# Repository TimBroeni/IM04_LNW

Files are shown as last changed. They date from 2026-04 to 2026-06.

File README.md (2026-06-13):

# Sortino

## Inhaltsverzeichnis

- [Kurzbeschreibung des Projekts](#kurzbeschreibung-des-projekts)
- [UX & Konzeption](#ux--konzeption)
- [Setup](#setup)
- [Technische Details](#technische-details)
- [Known bugs](#known-bugs)
- [Umsetzungsprozess](#umsetzungsprozess)

## Kurzbeschreibung des Projekts

* **Modul:** Interaktive Medien 4 an der Fachhochschule Graubünden (FS26)  
* **Themenfeld:** IoT-Applikation zum Thema Eltern mit kleinen Kindern  
* **Name des Projekts:** Sortino   
* **Team Physical Computing:** Carlo Pierotto & Luc Guerraz
* **Team WebApp:** Tim Brönimann, Tim Eberbard

Kinder räumen ungerne ihr Zimmer auf und Eltern haben es gern wenn es am Abend aufgeräumt ist. 
Unsere Kiste motiviert Kinder zum aufräumen, sie erlässt jeden Abend um 18:30 einen Reminder zum aufräumen und um 19:00 einen Lob oder eine Ermahnung ja nach dem ob aufgeräumt worden ist oder nicht.
Die Kiste erkennt Spielzeuge anhand des Gewichts. 
Über die Web-App können die Eltern einsehen, welche Spielzeuge gerade ausserhalb der Kiste sind, und welches die beliebtesten Spielzeuge sind.

* **WebApp:** [https://im04.tim-broenimann.ch](https://im04.tim-broenimann.ch)  
* **Video-Dokumentation:** [Link zum Video auf Youtube](https://www.youtube.com/watch?v=574Dd3WErXQ) 

## UX & Konzeption

*In diesem Teil werden die gemeinsamen Schritte aus der UX-Abgabe dokumentiert, damit sich hier alles vollständig an einem Ort befindet (betrifft WebApp und Physical Computing)*

### Figma:
[Link zum Figma](https://www.figma.com/design/I6OaVpQoHoBlVxiTwrd5Yo/App-Konzeption?node-id=0-1&t=EXwHhpwK3AQBsHQe-1)
### User Flow \+ Screen Flow (Screenshot aus Figma)
User Flow + Screen Flow
### Weitere Ergänzungen

#### Welche Features waren angedacht? 

##### Folgene Features wurden umgesetzt:

Die Aktuelle Webapp, so wie sie jetzt steht, enthält die Basis unserer geplanten Features. Die Webapp erlaubt es eine Spielzeugkiste zu haben, die jederzeit weiss, welche Spielzeuge akteull in der Spielzeugkiste sind und welche nicht. Anhand des Gewichts des Spielzeuges erkennt die Kiste, ob ein Speilzeug gerade in der Kiste ist oder nicht. Über die Spielzeug-Seite können die Spielzeuge verwaltet werden. Man kann neue Spielzeuge hinzufügen, ihnen neue Namen geben oder Spielzeuge wieder löschen (wenn man sie z.B. verkauft hat). Dort sieht man ebenfalls einen Überblick über die Nutzungshäufigkeit der Spielzeuge. In den Einstellungen kann ich mein Profil bearbeiten und meinen Haushalt verwalten. Das heisst, ich kann meinem Haushalt Kisten hinzufügen. Auf der Seite sehe ich meinen Haushaltscode mit welchem andere Erziehungsberechtigte meinem Haushalt beitreten können. Diese kann ich in den Einstellungen auch wieder entfernen (z.B. wenn sich die Eltern getrennt haben😢). Die Webapp wie sie jetzt entwickelt ist, ist für die Erziehungsberechtigten entwickelt. Somit kann die Bildschirmzeit der Kinder reduziert werden.

##### Und, folgende Features wurden nicht umgesetzt:

|Feature|Teil|Erklärung|
|-|-|-|
|Erkennung über RFID|MC|In der ersten Konzeptionsphase war die Idee, die spielzeuge anhand eines RFID-Chips zu erkennen. Über mehrere Antennen hätte die Box das Spielzeug automatisch erkennen sollen, wenn das Spielzeug mit dem Chip in die Box gesetzt wird.|
|Rollen für User|WebApp|Im Ursprünglichen System. Eltern erhalten Admin-Rechte für die Web-App. Kinder benötigen nicht zwingend Zugriff auf die Webapp, jedoch ist in der Webapp ersichtlich, welches Kind wie viele Punkte hat (also wie gut es aufträumt). Damit das System funktioniert, hätte die Box nicht einem Haushalt sondern einem User zugewiesen werden müssen. Die Punkte kann das Kind sammeln und gegen Belohnungen einlösen. Weil das Punktesystem wegfiel und Kisten direkt dem Haushalt hinzugefügt wurden, fiel das Rollensystem weg. Kinder können ohne Umstände die Box benutzen während die Eltern Kontrolle über die Box haben.|
|Gamification|WebApp|Punkte sammeln:<br>Jeden Abend um eine vordefinierte Uhrzeit gibt die Box ein Signal, dass es bald Zeit ist, aufzuräumen. Nach ca. 30 Minuten kontrolliert die Webapp automatisch, ob heute Spielzeuge genutzt wurden und ob alle Spielzeuge in der Kiste sind. Wenn zu diesem Zeitpunkt alles aufgeräumt ist, erhält das Kind einen Punkt. Über die Webapp können die Eltern mit ihren Adminrechten im Punkteverlauf ebenfalls Punkte hinzufügen, wenn das Kind z.B. im Haushalt mal ausserordentlich mitgeholfen hat. Die Eltern können dort ebenfalls erhaltene Punkte wieder löschen. Sowohl auf der Webapp wie auch auf dem physischen Display an der Box ist ersichtlich, wie viele Punkte gesammelt wurden und wie nah man an den Belohnungen ist. Dieses Feature wurde gestrichen um den Rahmen des Projektes nicht zu sprengen, weil die Webapp schon genug Features hatte und der Aufwand zu gross geworden wäre.<br><br>Punkte einlösen:<br>Über die Belohnungsseite können die Eltern für einen Haushalt Belohnungen definieren und die Belohnung den Kindern zuweisen. Die Eltern können festlegen, wie viele Punkte eine Belohnung kosten soll. Hat das Kind eine Belohnung eingelöst, müssen es die Eltern über die Webapp einlösen. Die Punkte werden vom aktuellen Punktestand abgezogen. Weil die Gamification weg fiel wurde das Belohnungssystem ebenfalls gestrichen.|
|Gamification|MC|Lange war geplant, der Box ein Aufräum-Feature zu verpassen. Dabei schlägt die Box vor, welches Spielzueg als nächstes eingeräumt werden sollte. Schafft man es innerhalb einer gweissen Ziet, erhält das Kind zusätzliche Punkte. Z.B. steht "Bring mir als nächstes das Piratenschiff" und ein Countdown. Dabei priorisiert die Box schwere Spielzeuge zuerst (siehe nächstes Feature). Dieses Feature wurde gestrichen um den Rahmen des Projektes nicht zu sprengen, weil die Webapp und MC schon genug Features hatte und der Aufwand zu gross geworden wäre.|
|Kategorien für Spielzeuge|WebApp|Ursprünglich war gedacht, dass man beim hinzufügen eines Spielzeuges klassifizierungen geben kann, z.B. ob ein Spielzeug schwer oder fragile ist. In der Aufräum-Gamification hätte die Box priorisieren sollen, zuerst schwere Spielzeuge einzuräumen und erst dann die leichten, welche schnell kaputt gehen können. Weil die Box-Gamification weg fiel, wurde diese Angabe bei den Speilzeugen entfernt. Das gewicht wird lediglich genutzt, weil anhand des Gewichts das jeweilige Spielzeug erkannt wird. Dieses Feature wurde nicht eingebaut, weil die Gamification weg fiel. Die Box musste nicht mehr zwingend wissen, welche Spielzeuge zuerst eingeräumt werden müssen. Deswegen wurde dieses Feature überflüssig.|
|Kontrolle über Gamification|WebApp|In der Webapp sollte es in einem Haushalt mehrere Rollen geben. Eltern hätten Admin-Rechte und könnten Einstellungen an der Gamification vornehmen z.B. wie viel Punkte das Kind fürs Aufräumen bekommt, wie viele Punkte eine Belohnung kostet, wann der Stichzeitpunkt wo die Kiste kontrolliert, ob alles versorgt ist und man hätte einstellen können, wie hoch die Toleranz ist, wie viele Spielzeuge über nach draussen bleiben dürfen. Das Kind hätte dann trotzdem einen Punkt erhalten, auch wenn z.B. zwei Spielzeuge nicht eingeräumt sind. Die Gamification hätte man auch vollkommen deaktivieren können. Dann würde das Punktesystem für den Entsprechenden Haushalt deaktiviert sein. Weil die Gamification weg fiel müssen die Game-Settings nicht mehr eingestellt werden.|

## Setup

### Installationsanleitung WebApp

#### Infrastruktur + Installation
Für die Webapp wird ein Hosting mit einer Domain benötigt. Als Beispiel eignen sich Anbieter wie Infomaniak oder Hostpoint. Dort laufen sowohl die Webseite als auch die Datenbank. Die Webapp selbst besteht aus PHP, JavaScript sowie HTML/CSS.
Zusätzlich wird eine MySQL-Datenbank benötigt, welche über das Hosting erstellt werden kann. Der Zugriff auf die Datenbank erfolgt über phpMyAdmin. Damit sich die Webseite mit der Datenbank verbinden kann, müssen die Zugangsdaten in der Datei config.php eingetragen werden. Dazu gehören der Host, der Datenbankname, der Benutzername sowie das Passwort.
Wichtig ist, dass die config.php Datei nicht öffentlich auf GitHub hochgeladen wird, da sie sensible Zugangsdaten enthält. Deshalb sollte sie über die .gitignore Datei ausgeschlossen werden.
Für die Zusammenarbeit im Team wurde GitHub verwendet. Alternativ könnte auch eine andere Plattform zur Versionsverwaltung genutzt werden. Der Code kann anschliessend über eine SFTP-Verbindung direkt auf den Webserver hochgeladen und synchronisiert werden.
Die physische Sortino-Box benötigt ausserdem eine Stromversorgung sowie eine WLAN-Verbindung aus dem Haushalt, damit sie mit der Datenbank kommunizieren kann.

#### Datenbank importieren und verbinden
Die Datenbank kann direkt über das Hosting erstellt werden. Danach werden die benötigten Tabellen in die Datenbank importiert. In unserem Fall enthält die Datenbank unter anderem Tabellen für Haushalte, Benutzer:innen, Kisten sowie Spielzeuge und das Heraus-/Zurücklegen der Spielzeuge.
Im Projekt befindet sich zusätzlich eine db.sql Datei. Diese enthält die Struktur der gesamten Datenbank und kann über phpMyAdmin importiert werden. Dadurch werden alle benötigten Tabellen automatisch erstellt.
Damit die Webapp auf diese Daten zugreifen kann, muss die Verbindung in der config.php Datei eingerichtet werden. Dort werden die Zugangsdaten der Datenbank eingetragen. Dazu gehören der Host, der Datenbankname, der Benutzername und das Passwort.
Nach der erfolgreichen Verbindung kann die Webapp Daten lesen und neue Informationen abspeichern. Dazu gehören beispielsweise neue Haushalte, registrierte Kisten oder die gespeicherten Gewichte der Spielzeuge.
Die Kommunikation zwischen der Sortino-Box und der Webapp läuft über die Datenbank. Die Box speichert neue Informationen direkt dort ab. Die Webapp liest diese Daten anschliessend aus und stellt sie für die Eltern übersichtlich dar.
Dadurch kann später angezeigt werden:
•	welche Spielzeuge momentan fehlen
•	wann ein Spielzeug zuletzt verwendet wurde
•	wie oft ein Spielzeug aus der Kiste genommen wurde
•	welche Kisten zu einem Haushalt gehören
Ein Haushalt kann mehrere Kisten besitzen. Die Daten (Spielzeuge) aller Kisten werden anschliessend gemeinsam in der Webapp dargestellt.

#### Erststart der Webapp und Einrichtung
Nach dem Kauf der Sortino-Box besucht der User zuerst die Sortino-Webseite. Die Startseite der Webapp ist gleichzeitig die Login- und Registrierungsseite.
Zuerst wird ein Benutzerkonto mit Name, E-Mail-Adresse und Passwort erstellt. Nach dem ersten Login erkennt die Webapp, dass der Account noch keinem Haushalt zugeordnet ist.
Anschliessend kann entweder einem bestehenden Haushalt über einen Code beigetreten oder ein neuer Haushalt erstellt werden. Beim Erstellen eines neuen Haushalts wird dessen Name in der Datenbank gespeichert und mit einer eigenen household_id versehen.
Danach kann die gekaufte Sortino-Box hinzugefügt werden. Dazu wird die Seriennummer verwendet, welche auf der Unterseite der Box eingraviert ist. Diese Seriennummer ist bereits in der Datenbank vorhanden, jedoch noch keinem Haushalt zugewiesen.
Sobald die Kiste erfolgreich verbunden wurde, kann ihr ein eigener Name gegeben werden. Dies ist beispielsweise sinnvoll, wenn mehrere Kinder oder mehrere Kisten in einem Haushalt vorhanden sind.
Im letzten Schritt können Spielzeuge hinzugefügt werden. Dafür wird einem Spielzeug zuerst in der Webapp ein Name gegeben. Anschliessend wird das Spielzeug in die Kiste gelegt. Die Box erkennt die Gewichtsveränderung und speichert diese zusammen mit der passenden household_id in der Datenbank ab.
Dadurch kann später erkannt werden, wann ein Spielzeug aus der Kiste genommen oder wieder zurückgelegt wurde.

### Bauanleitung Physical Computing

Um das physische Artefakt nachbauen zu können muss mann die Komponenten nach Komponentenliste & Steckplan zusammen bauen. Danach müssen die WLAN Credentials in der `sortino_OS.ino`-Datei hinterlegt werden, sie muss anschliessend kompiliert werden und auf das Microcontroller hochladen werden.

#### Komponenten
- ESP32C6
- OLED Display
- MP3 Player mit Lautsprecher
- LED Ring (12 LEDs)
- Gewichtssensor

Der ESP32C6 ist das Kernstück, woran alle Physischen Komponenten verbunden werden.
Im Steckplan sieht man, an welche Pins, welche Komponenten angeschlossen werden.

#### Steckplan
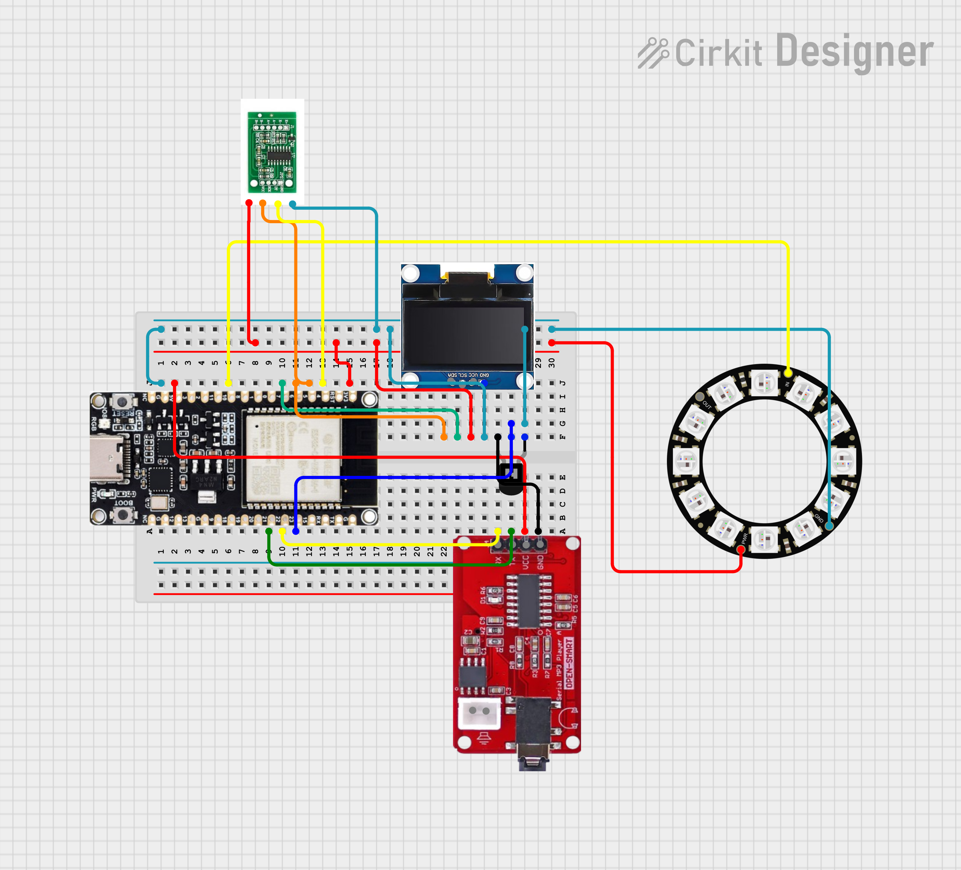
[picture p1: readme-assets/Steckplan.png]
Steckplan


#### Programme

|Datei|Rolle|
|--|--|
|`sortino_OS.ino`|Das Hauptprogramm, welches Setup und Loop festlegt. Im Setup wird die WLAN-Verbindung erstellt und sowohl der Gewichtssensor als auch der Audioplayer initialisiert. In der Loop wird die Uhrzeit überprüft, um den Aufräum-Reminder auszulösen. Es wird nach Gewichtsänderungen überprüft, um das Reinlegen oder Herausnehmen von Spielzeugen zu erfassen. Ebenso wird nach dem `add_mode` überprüft, um neue Spielzeuge zu erfassen.|
|`cJSON/cJSON.c`|Arduino JSON Library|
|`cJSON/cJSON.h`|Arduino JSON Library|
|`Adafruit_BusIO_Register.cpp`|Arduino Adafruit GFX dependency. Arduino Adafruit Bus IO Library|
|`Adafruit_BusIO_Register.h`|Arduino Adafruit GFX dependency. Arduino Adafruit Bus IO Library|
|`Adafruit_GenericDevice.cpp`|Arduino Adafruit GFX dependency. Arduino Adafruit Bus IO Library|
|`Adafruit_GenericDevice.h`|Arduino Adafruit GFX dependency. Arduino Adafruit Bus IO Library|
|`Adafruit_GFX.cpp`|OLED Display funktionalität. Arduino Adafruit GFX Library|
|`Adafruit_GFX.h`|OLED Display funktionalität. Arduino Adafruit GFX Library|
|`Adafruit_I2CDevice.cpp`|Arduino Adafruit GFX dependency. Arduino Adafruit Bus IO Library|
|`Adafruit_I2CDevice.h`|Arduino Adafruit GFX dependency. Arduino Adafruit Bus IO Library|
|`Adafruit_I2CRegister.h`|Arduino Adafruit GFX dependency. Arduino Adafruit Bus IO Library|
|`Adafruit_NeoPixel.cpp`|LED Ring funktionalität. Arduino Adafruit NeoPixel Library|
|`Adafruit_NeoPixel.h`|LED Ring funktionalität. Arduino Adafruit NeoPixel Library|
|`Adafruit_SPIDevice.cpp`|Arduino Adafruit GFX dependency. Arduino Adafruit Bus IO Library|
|`Adafruit_SPIDevice.h`|Arduino Adafruit GFX dependency. Arduino Adafruit Bus IO Library|
|`Adafruit_SSD1306.cpp`|OLED Display funktionalität. Arduino Adafruit SSD1306 Library|
|`Adafruit_SSD1306.h`|OLED Display funktionalität. Arduino Adafruit SSD1306 Library|
|`Arduino_JSON.h`|Arduino JSON Library|
|`audioplayer.h`|Audio player funktionalität. Diese Datei wird in mc.ino eingebunden.|
|`esp.c`|LED Ring funktionalität. Arduino Adafruit NeoPixel Library|
|`gfxfont.h`|OLED Display funktionalität. Arduino Adafruit GFX Library|
|`glcdfont.c`|OLED Display funktionalität. Arduino Adafruit GFX Library|
|`HX711.cpp`|Gewichsensor funktionalität. Arduino HX711 Library|
|`HX711.h`|Gewichsensor funktionalität. Arduino HX711 Library|
|`JSON.cpp`|Arduino JSON Library|
|`JSON.h`|Arduino JSON Library|
|`JSONVar.cpp`|Arduino JSON Library|
|`JSONVar.h`|Arduino JSON Library|
|`splash.h`|OLED Display funktionalität. Arduino Adafruit SSD1306 Library|

#### Kommunikationswege / API Schnittstellen

##### Kisten status abfragen (`api/physical/lib/get/add.php`)
Wird alle 3 Sekunden abgefragt, um zu wissen ob die Kiste neue Spielzeuge jetzt messen muss
```bash
curl -X GET 'https://im04.tim-broenimann.ch/api/physical/[seriennumer]/add'
```
```json
{
  "status": "success",
  "data": {
    "add_mode": false
  }
}
```

##### Spielzeug hinzufügen, gewicht erfassen (`api/physical/lib/post/add.php`)
Wird abgefragt, um das Gewicht eines neues Spielzeug zu erfassen
```bash
curl -X POST 'https://im04.tim-broenimann.ch/api/physical/[seriennumer]/add' \
  --header 'Content-Type: application/json' \
  --data '{"weight": 140}'
```
```json
{
  "status": "success",
  "data": {
    "name": "Neues Spielzeug Name"
  }
}
```

##### Spielzeug wird in kiste gelegt/herausgenommen (`api/physical/lib/post/event.php`)
Wird abgefragt, um eine Gewichtänderung in der Kiste zu erfassen.
```bash
curl -X POST 'https://im04.tim-broenimann.ch/api/physical/[seriennumer]/event' \
  --header 'Content-Type: application/json' \
  --data '{"weight": 87.0}'
```
```json
{
  "status": "success",
  "data": {
    "name": "Spielzeug Name",
    "movement": 1
  }
}
```

##### Sind alle Spielzeuge in der Kiste (`api/physical/lib/get/status.php`)
Wird abgefragt, um zu wissen ob alle Spielzeuge in der Kiste sind und zu wissen wieviele fehlen/da sind
```bash
curl -X GET 'https://im04.tim-broenimann.ch/api/physical/[seriennumer]/status'
```
```json
{
  "status": "success",
  "data": {
    "all_in_box": true,
    "in_box": 14,
    "out_box": 0
  }
}
```

## Technische Details

### Komponentenplan

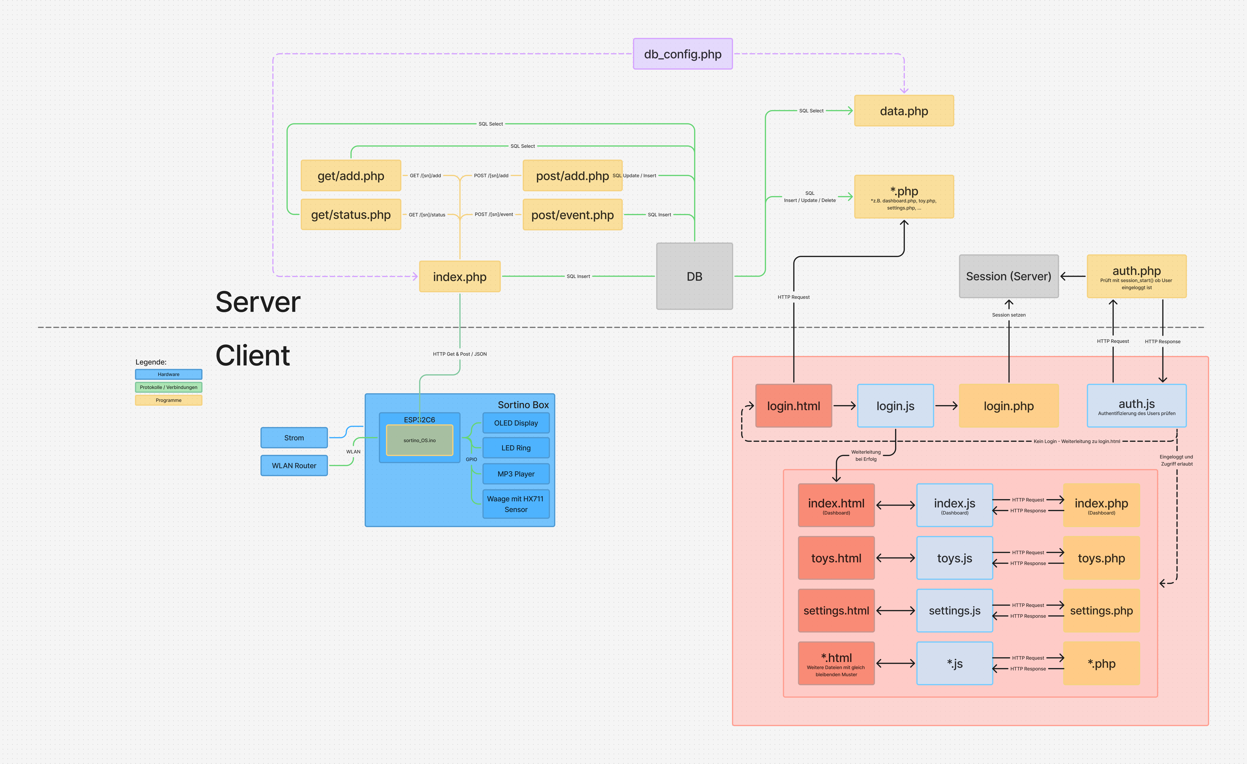
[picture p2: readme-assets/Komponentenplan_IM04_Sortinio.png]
Komponentenplan


### Projektstruktur / Code-Struktur \[*Hinweis: Der Code selbst muss im Repository liegen und im Kopfbereich jeder Datei eine kurze Zusammenfassung enthalten.*\] 

```
.
├── api                                         ← Alle Backend-Endpoints (geben JSON zurück)
│   ├── physical                                ← Microcontroller Endpoints
│   │   ├── lib                                 ← Programm Code
│   │   │   ├── get                             ← alle GET Methoden
│   │   │   │   ├── add.php                     ← Kisten "add_mode" Status laden
│   │   │   │   └── status.php                  ← Kisten Inhalt Status laden
│   │   │   ├── post                            ← alle POST Methoden
│   │   │   │   ├── add.php                     ← Spielzeug Gewicht erfassen
│   │   │   │   └── event.php                   ← Kiste Gewichtänderung verarbeiten
│   │   │   └── .htaccess                       ← verbeitet direkter Zugang zur lib
│   │   ├── .htaccess                           ← leitet alle Anfragen auf index.php
│   │   └── index.php                           ← vorsortiert Anfragen und führt Code der lib aus
│   ├── add_toy.php                             ← Spielzeug hinzufügen
│   ├── auth.php                                ← Session-Status prüfen
│   ├── dashboard.php                           ← Dashboard-Daten laden
│   ├── household.php                           ← Haushalt verwalten
│   ├── login.php                               ← Login verarbeiten
│   ├── logout.php                              ← Session beenden
│   ├── name_toy.php                            ← Spielzeug umbenennen
│   ├── new_box.php                             ← Neue Kiste hinzufügen
│   ├── newhousehold.php                        ← Neuen Haushalt erstellen
│   ├── profil.php                              ← Profildaten laden
│   ├── profilUpdate.php                        ← Profil aktualisieren
│   ├── register.php                            ← Registrierung verarbeiten
│   ├── settings.php                            ← Einstellungen speichern
│   ├── toy.php                                 ← Spielzeugdaten laden
│   └── toyUpdate.php                           ← Spielzeug aktualisieren
├── css                                         
│   ├── desktop.css                             ← Desktop-Layout
│   ├── master.css                              ← Globale Basisstile
│   └── mobile.css                              ← Mobile Darstellung
├── images                                     
│   ├── nav                                     
│   │   ├── nav_gifts.svg                       ← Icon für Belohnungen
│   │   ├── nav_home.svg                        ← Icon für Startseite
│   │   ├── nav_points.svg                      ← Icon für Punkte
│   │   ├── nav_settings.svg                    ← Icon für Einstellungen
│   │   └── nav_toys.svg                        ← Icon für Spielzeuge
│   ├── DEMO_toy_loeschen.png                   ← Demo für Löschen
│   ├── DEMO_toy_update.png                     ← Demo für Bearbeiten
│   ├── sortino_bildmarke.png                   ← Bildmarke von Sortino
│   ├── sortino_favicon.png                     ← Favicon der WebApp
│   ├── sortino_marke.png                       ← Markenlogo von Sortino
│   └── sortino_textmarke.png                   ← Textlogo von Sortino
├── js                                          
│   ├── add_toy.js                              ← Spielzeug hinzufügen
│   ├── auth.js                                 ← Authentifizierung prüfen
│   ├── dashboard.js                            ← Dashboard steuern
│   ├── data.js                                 ← Gemeinsame Datenladefunktionen
│   ├── join_household.js                       ← Haushalt beitreten
│   ├── login.js                                ← Login-Formular steuern
│   ├── logout.js                               ← Logout ausführen
│   ├── name_toy.js                             ← Spielzeugname ändern
│   ├── new_box.js                              ← Kiste anlegen
│   ├── new_household.js                        ← Haushalt anlegen
│   ├── profil.js                               ← Profilseite steuern
│   ├── register.js                             ← Registrierung steuern
│   ├── settings.js                             ← Einstellungen steuern
│   └── toy.js                                  ← Spielzeugseite steuern
├── pysical                                     ← Alles für den Microcontroller
│   ├── 3D Druck
│   │   └── 3d Druck.3mf                        ← 3D Model für die Kiste
│   ├── Audios                                  ← Audios für die SD Karte der Audio Interface
│   │   ├── 01.mp3
│   │   ├── 02.mp3
│   │   └── 03.mp3
│   └── sortino_OS                              ← Arduino Projekt
│       ├── cJSON                               ← Arduino Libraries
│       │   ├── cJSON.c                         ← Arduino Libraries
│       │   ├── cJSON.h                         ← Arduino Libraries
│       │   └── LICENSE                         ← Arduino Libraries
│       ├── Adafruit_BusIO_Register.cpp         ← Arduino Libraries
│       ├── Adafruit_BusIO_Register.h           ← Arduino Libraries
│       ├── Adafruit_GenericDevice.cpp          ← Arduino Libraries
│       ├── Adafruit_GenericDevice.h            ← Arduino Libraries
│       ├── Adafruit_GFX.cpp                    ← Arduino Libraries
│       ├── Adafruit_GFX.h                      ← Arduino Libraries
│       ├── Adafruit_I2CDevice.cpp              ← Arduino Libraries
│       ├── Adafruit_I2CDevice.h                ← Arduino Libraries
│       ├── Adafruit_I2CRegister.h              ← Arduino Libraries
│       ├── Adafruit_NeoPixel.cpp               ← Arduino Libraries
│       ├── Adafruit_NeoPixel.h                 ← Arduino Libraries
│       ├── Adafruit_SPIDevice.cpp              ← Arduino Libraries
│       ├── Adafruit_SPIDevice.h                ← Arduino Libraries
│       ├── Adafruit_SSD1306.cpp                ← Arduino Libraries
│       ├── Adafruit_SSD1306.h                  ← Arduino Libraries
│       ├── Arduino_JSON.h                      ← Arduino Libraries
│       ├── audioplayer.h                       ← Arduino Libraries
│       ├── esp.c                               ← Arduino Libraries
│       ├── gfxfont.h                           ← Arduino Libraries
│       ├── glcdfont.c                          ← Arduino Libraries
│       ├── HX711.cpp                           ← Arduino Libraries
│       ├── HX711.h                             ← Arduino Libraries
│       ├── JSON.cpp                            ← Arduino Libraries
│       ├── JSON.h                              ← Arduino Libraries
│       ├── JSONVar.cpp                         ← Arduino Libraries
│       ├── JSONVar.h                           ← Arduino Libraries
│       ├── sortino_OS.ino                      ← Microcontroller Code 
│       └── splash.h                            ← Arduino Libraries
├── readme-assets                               ← Bilder für das ReadMe
│   ├── ERM.png
│   ├── ScreenFlow.png
│   └── Steckplan.png
├── system                                      ← System- und Datenbankdateien
│   ├── config.php                              ← Datenbankkonfiguration
│   ├── config.php.blank                        ← Vorlage für config.php
│   └── db.sql                                  ← Datenbankschema
├── .gitattributes
├── .gitignore
├── add_toy.html                                ← Seite zum Hinzufügen
├── household.html                              ← Haushaltsübersicht
├── index.html                                  ← Einstiegsseite
├── join_household.html                         ← Seite zum Beitritt
├── login.html                                  ← Login-Seite
├── name_toy.html                               ← Seite zum Umbenennen
├── new_box.html                                ← Seite zum Kiste anlegen
├── new_household.html                          ← Seite zum Haushalt anlegen
├── profil.html                                 ← Profilseite
├── README.md                                   ← Github ReadMe
├── register.html                               ← Registrierungsseite
├── settings.html                               ← Einstellungsseite
└── toys.html                                   ← Spielzeugübersicht
```

### Datenschnittstelle
Die `toy_events` und `boxes` Tabellen dienen zur Schnittstelle zwischen das Microcontroller und der Webapp.

Wenn ein Spielzeug aus der Kiste genommen wird, wird ein Eintrag in der `toy_events` Tabelle gemacht.

Wenn man in der App ein neues Spielzeug erfassen will, wird in der `boxes` Tabelle der `add_mode` auf `true` gesetzt, und ein neuer Eintrag in der `toys` Tabelle erstellt, mit einem `weight` von `0`. Wenn 15s nichts in die Box gelegt wird, bricht die App den Vorgang ab. 
Der MC fragt alle drei Sekunden dem Server nach ob die Kisten im add_mode ist, und wenn ja erfasst es das neue Gewicht im `toy` Eintrag von vorher.

### ERM
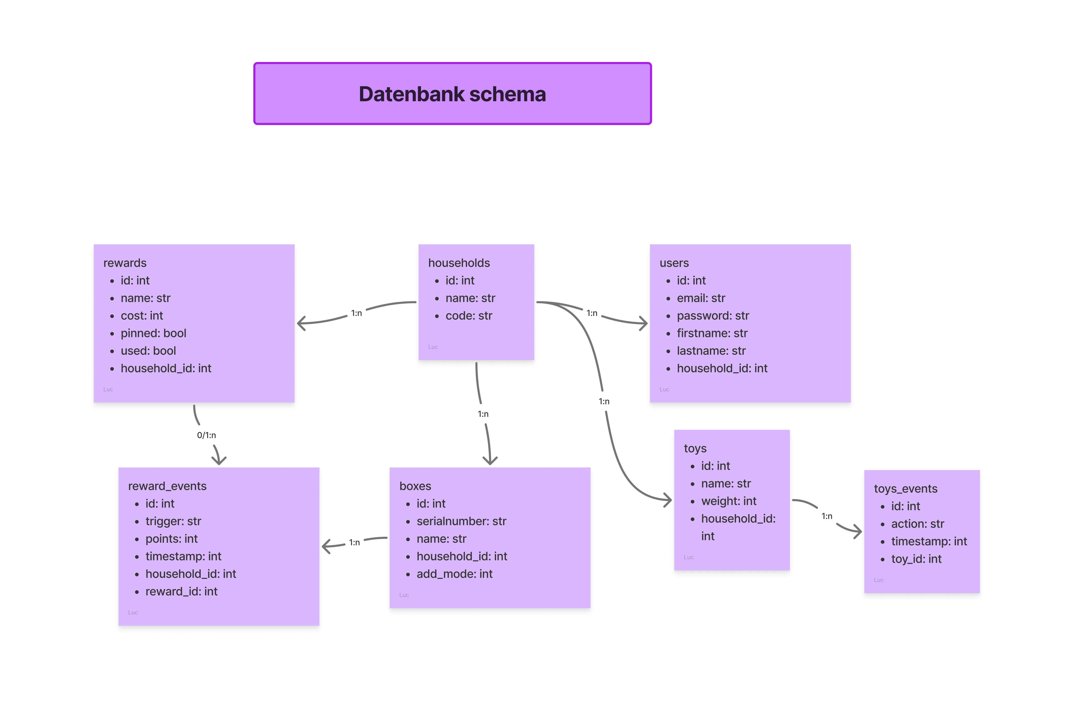
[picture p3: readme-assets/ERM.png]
ERM Diagramm
 
- **households**
  - Zentrale Tabelle für Haushalte/Familien
  - Attribute:
    - `id`
    - `name`
    - `code`
  - Beziehung:
    - Ein Haushalt kann mehrere Benutzer, Kisten und Belohnungen besitzen.

- **users**
  - Speichert Benutzer eines Haushalts
  - Attribute:
    - `id`
    - `email`
    - `password`
    - `firstname`
    - `lastname`
    - `household_id`
  - Beziehung:
    - Mehrere Benutzer gehören zu einem Haushalt.

- **boxes**
  - Speichert Spielzeugkisten eines Haushalts
  - Attribute:
    - `id`
    - `serialnumber`
    - `name`
    - `add_mode`
    - `household_id`
  - Beziehung:
    - Ein Haushalt kann mehrere Kisten besitzen.

- **toys**
  - Speichert Spielzeuge innerhalb einer Kiste
  - Attribute:
    - `id`
    - `name`
    - `weight`
    - `household_id`
  - Beziehung:
    - Ein Haushalt kann mehrere Spielzeuge enthalten.

- **toys_events**
  - Speichert Aktionen/Ereignisse zu Spielzeugen
  - Attribute:
    - `id`
    - `timestamp`
    - `movement`
    - `toy_id`
    - `box_id`
  - Beziehung:
    - Ein Spielzeug kann mehrere Events besitzen.

- **rewards**
  - Speichert Belohnungen eines Haushalts
  - Attribute:
    - `id`
    - `name`
    - `cost`
    - `pinned`
    - `used`
    - `household_id`
  - Beziehung:
    - Ein Haushalt kann mehrere Belohnungen besitzen.

- **reward_events**
  - Speichert ausgelöste Belohnungsereignisse und Punkte
  - Attribute:
    - `id`
    - `trigger`
    - `points`
    - `timestamp`
    - `household_id`
    - `reward_id`
  - Beziehung:
    - Verknüpft Boxen mit Belohnungen und dokumentiert Punkte/Ereignisse.

### Authentifizierung
Die Authentifizierung der Webapp basiert auf PHP-Sessions. Dadurch erhalten nur angemeldete Benutzer:innen Zugriff auf geschützte Seiten und ihre Daten.
Das Login startet auf der `login.html` Seite. Die eingegebenen Login-Daten werden über `login.js` an `login.php` gesendet. Dort werden E-Mail-Adresse und Passwort mit den gespeicherten (und zum teil verschlüsselten) Daten aus der Datenbank verglichen. Für die Passwortprüfung wird `password_verify()` verwendet. Falls die Daten korrekt sind, startet `login.php` die Session. In den PHP-Dateien wird dafür jeweils `session_start()` benötigt, damit auf die Session zugegriffen werden kann. In der Session werden unter anderem `user_id`, E-Mail-Adresse und `household_id` gespeichert.

Beim Laden geschützter Seiten wird automatisch `auth.js` ausgeführt. Diese Datei sendet eine Anfrage an `auth.php`, um zu prüfen, ob noch eine gültige Session vorhanden ist. Falls keine gültige Session existiert, liefert `auth.php` einen `401 Unauthorized` Fehler zurück. `auth.js` leitet den User anschliessend automatisch zurück auf `login.html`. Falls die Session gültig ist, werden `user_id` und E-Mail-Adresse als JSON zurückgegeben.

Weitere Benutzerdaten werden über `profil.php` geladen und in `profil.js` zusammen mit `data.js` verwendet. Auch dort wird zuerst überprüft, ob eine gültige Session vorhanden ist. Die Abmeldung erfolgt über `logout.php`. Dabei wird die aktuelle Session gelöscht und der Benutzer ausgeloggt.

Vereinfachter Datenfluss:
`login.html → login.js → login.php → Datenbank → Session`

Geschützte Seiten:
`auth.js → auth.php → Sessionprüfung → Zugriff erlauben oder Login`

## Known bugs / wichtige Ergänzungen

### User löscht sich selber
Wenn der aktuelle User sich selber aus dem Haushalt entfernen möchte, funktioniert das. Das ist in erster Linie bereits ein wenig fragwürdig. Andererseits wird er dann nicht zurück zu login.html zurückgeschickt, sondern bleibt in der Webapp drinn. Aber da er keinem Haushalt zugehörig ist, werden keine Daten angezeigt und es ist einfach alles auf "0" oder leer.

### Noch keine Spielzeuge
Wenn der User einen neuen Haushalt erstellt, die Spielzeuge aber ist in einem zweiten Schritt hinzufügt, wird ihm auf dem Dashboard trotzdem in grün "Alles aufgeräumt" angezeigt. Optimal wäre wenn hier wie bei toys.html stehen würde, dass zuerst ein Spielzeug hinzugefügt werden sollte.

### Spielzeuge nach Kiste sortieren
Aktuell werden unter toys.html alle Spielzeuge untereinander aufgelistet. Hat der User aber 3 Kisten mit je 20 Spielzeuge kann das etwas unübersichtlich werden. Hier wäre ein Button, der nach Kiste A, B oder C filtern könnte optimal für eine bessere Übersicht.

### Aufräumzeit verwalten
Aktuell fehlt in den Einstellungen noch die Möglichkeit die Uhrzeit einzustellen, bei der das Kind alles aufgerämt haben muss. 

### Spielzeuge hinzufügen
Wir sind uns unsicher, ob das "+" unter toys.html genügen versätnlich ist. Hiermit sollen neue Spielzeuge hinzugefügt werden. Evtl wäre es besser gewesen dies auszuschreiben, damit es direkt erkennbar wird.

### RFID statt Gewicht
Es wäre definitiv sinnvoller mit RFID statt mit einer Waage zu arbeiten. Die Waage funktioniert nur dann gut, wenn die Spielzeuge mit etwas Schwung hineingelegt werden. Nur so checkt die Waage, dass ein Unterschied entstanden ist und kann das Spielzeug korrekt bemessen. RFID's wären genauer und würden auch mehrere Spielsachen gleichzeitig erkennen.

### Nutzungshäufigkeits-Tabelle
Aktuell werden immer alle Spielzeuge angezeigt. Egal ob sie vor 7 Tagen verwendet wurden oder nicht. Optimaler wäre, wenn nur Spielsachen angezeigt werden, die in den letzten 7 Tagen auch wirklich genutzt wurden. Evtl schadet dies ein wenig der Übersichtlichkeit. Aber das liegt aktuell vermutlich daran, dass es jeweils nur sehr wenige Spielzeuge sind.

<!-- * Was funktioniert noch nicht einwandfrei?  
* Was ist uns aufgefallen bei der Entwicklung?  
* Was könnte noch verbessert werden? -->

## Umsetzungsprozess //Alle

### Zu viel vorgenommen
Zu Beginn waren wir deutlich übermotiviert. Es wäre sehr toll gewesen alle Features und Details umzusetzen. Das wäre aber leider deutlich zu viel Arbeit für uns geworden. Dementsprechend sind wir aber happy mit dem Endresultat wie es herausgekommen ist. Trotzdem juckt es aber in den Fingern weiterzumachen und alle möglichen Funktionen noch ergänzen.

### KI-Nutzung
Vergangene Semester habe ich häufig mit ChatGPT gearbeitet. Dort jeweils mühsam den gesamten Code hochgeladen und versucht herauszufinden was ich wo jetzt neu einfügen muss, damit das Problem gelöst werden konnte. Das war bei diesem Projekt zu Beginn ebenfalls der fall, bis ich den Copilot in VS Code entdeckte. 
Ich finde es großartig, dass man bestimmte Dateien wie register.html und register.js auswählen, einen Prompt formulieren und den Code lesen und bearbeiten kann. So ist es immer klar was die KI berücksichtigen sollte und für mich einfacher nicht alles 100x kopieren und einfügen zu müssen. 
Mithilfe der KI hat der Programmieraspekt auch wirklich Spass gemacht. Man musste sich immernoch überlegen was will ich genau erreichen. Was brauche ich aus der DB und wie will ich es nutzen um mir etwas in der Webapp anzeigen zu lassen. Aber der schwierige Schreibaspekt mit der immernoch komplizierten Syntax wurde erleichtert.
Grundsätzlich habe ich immer überprüft was die KI jetzt neu gecodet / gelöscht hat. So habe ich vermieden, dass er aus welchen Gründen (vermutlich aufgrund meines unvollständigen Promptes) alles löscht und dabei eig mein Prompt falsch verstanden hatte. Mit der Zeit nahm aber das Vertrauen in Copilot zu und ich überprüfte weniger seinen Code und war ehrlich gesagt wengier gewollt alles verstehen zu wollen.
Jedenfalls habe ich den Code zu Beginn nicht direkt angenommen, sondern zuerst auf dem Browser getestet. Erst wenn es funktioniert hatte, nahm ich es an. Zum Teil habe ich den neuen Code auch ChatGPT als Zweitmeinung dazugezogen, ob und warum ein gewisser neuer Codeteil entstanden ist. Das hat sehr gut und effizient funktioniert.
Mit diesem Tool an der Seite fühlt sich IM aber deutlich weniger kompliziert, weniger stressig und effektiv machbar an, was ein schönes Gefühl ist :D. 

### Fazit
Das Projekt hat alles in allem eigentlich Spass gemacht. Vorallem in jenen Momenten, als die Webapp mit der Box harmoniesiert hat und wir Spielzeuge versorgen und hinausnehmen konnten. Der Start war mühsahm, als man wieder in den IM-Modus hineinfinden musste. Sobald aber bei der Webapp der Login/Registrierung/Session Aspekt erledigt war, wurde es weniger kompliziert und machbarer. 
Es ist aber ein tolles Gefühl so eine Webapp entwickelt zu haben, die wirklich so (natürlich noch etwas ausgebauter) auf dem Markt sein könnte, und es vergleichbar mit bestehenden Apps viele ähnliche Funktionen enthält. 

<!-- * **Reflexion / Erfahrung / Lernfortschritt:** *Was haben wir gelernt? Würden wir es nochmal genauso machen? Was war gut, was war schlecht?*  
* **Herausforderungen & Lösungen:** \[*Verworfene Ansätze, Fehler, Umplanungen*\]  
* **KI-Einsatz:** *Dokumentation der verwendeten KI-Tools und deren Nutzen (KI ist nicht verboten)*  
* **Fazit:** … -->

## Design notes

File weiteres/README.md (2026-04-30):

# 🔑👤 Authentifizierung Minimal (Boilerplate)





> 🎨 Dieses Boilerplate kann entweder in einem Code-Along Schritt für Schritt gemeinsam erarbeitet werden oder fixfertig auf einem Webserver installiert werden.

Dieses Repository beinhaltet ein vollständiges, minimales Authenzifizierungs-System basierend auf PHP als Backend und HTML/CSS/JS als Frontend.

Es ermöglicht Benutzern das `Registrieren`, `Anmelden`, `Abmelden` und den Zugriff auf eine `geschützte Seite` nach erfolgreicher Authentifizierung.

Eine einfache Erklärung des Login-Ablaufs mit Sessions und Cookies findest du in [`sessions.md`](sessions.md).

# 🏁 Live - Version

Du kannst Homely unter folgendem Link testen:

[https://im4.crazy-internet.ch/](https://im4.crazy-internet.ch/)

## ⚙️ Installation

Um dieses Boilerplate auf dem eigenen Web-Server zu installieren, führe folgende Schritte aus:

### 1. Download

- [Klone das Repository](https://docs.github.com/en/repositories/creating-and-managing-repositories/cloning-a-repository) über GitHub oder [downloade das Repository als ZIP Datei](https://docs.github.com/en/repositories/working-with-files/using-files/downloading-source-code-archives) auf deinen eigenen Computer.

### 2. Datenbank

- Erstelle eine neue Datenbank bei deinem Hoster (z.B. [Infomaniak](https://www.infomaniak.com/de/support/faq/1981/mysqlmariadb-benutzer-und-datenbanken-verwalten)).

- Importiere die Datei `system/database.sql` in die neue Datenbank, um die `users` Tabelle zu erstellen.

### 3. Code

- Benenne die Datei `system/config.php.blank` in `system/config.php` um.

- Passe die Datenbankverbindungsdaten in der Datei `system/config.php` an.

### 4. FTP Connect

- Erstelle eine neue FTP Verbindung mit dem SFTP Plugin gemäss [Anleitung im MMP 101](https://github.com/Interaktive-Medien/101-MMP/blob/main/resources/sftp.md).

# 📁 Struktur

## 🎨 Frontend

### root (Basis-Verzeichnis)

- beinhaltet alle HTML-Dateien des Frontends.
- beinhaltet die `.gitignore` Datei, welche die Dateien und Verzeichnisse ausblendet, die nicht auf GitHub hochgeladen werden sollen.

### js

- beinhaltet alle JavaScript-Dateien des Frontends.

### css

- beinhaltet alle CSS-Dateien des Frontends.

## 🤖 Backend

### api

- Beinhaltet alle API-Endpunkte des Backends.
- Diese Dateien werden von `JavaScript` aufgerufen und geben eine Antwort an `JavaScript` zurück.

### system

- Beinhaltet die Konfigurationsdatei für die Datenbankverbindung.
- Beinhaltet die Datei `database.sql`, die die `users` Tabelle erstellt.
- Beinhaltet die Datei `config.php`, die die Konfiguration des Backends enthält.

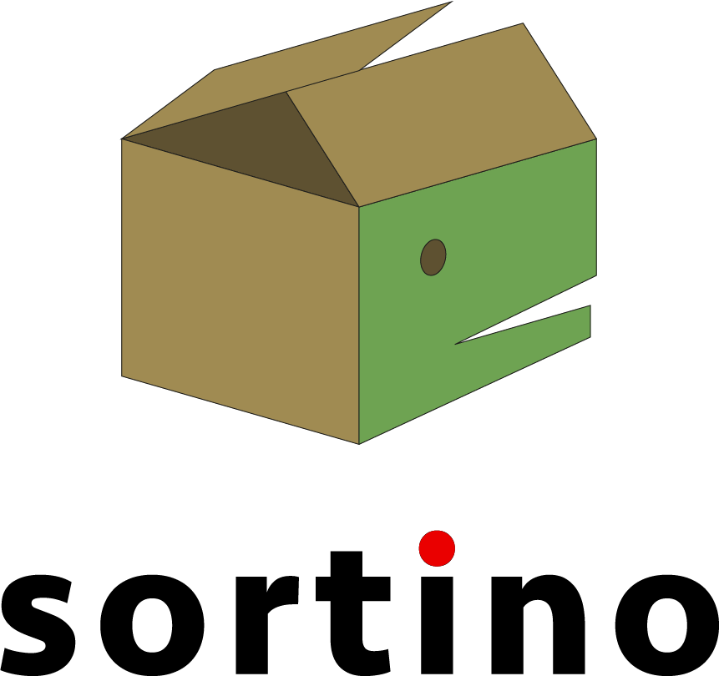
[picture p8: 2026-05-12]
images/sortino_marke.png

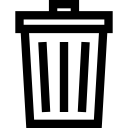
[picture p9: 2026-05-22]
images/DEMO_toy_loeschen.png

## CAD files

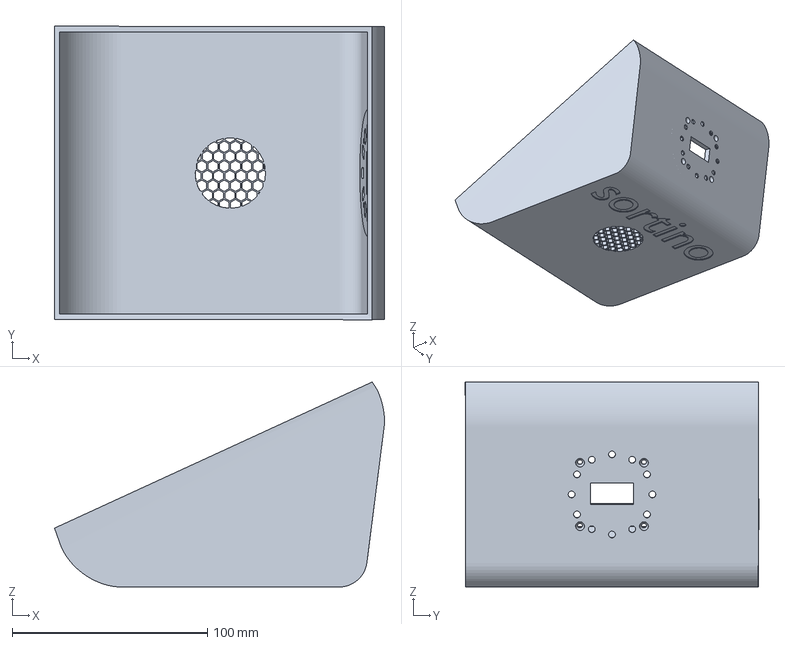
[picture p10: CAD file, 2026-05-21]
pysical/3D Druck/3d Druck.3mf
169.1 x 150.5 x 105.0 mm

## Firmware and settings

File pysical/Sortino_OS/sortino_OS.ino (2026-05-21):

/*
Das hier ist das Betriebssystem für sortino.
Dieses Projekt wurde im Rahmen vom Modul Interaktive Medien 4 von Tim Brönimann, Tim Eberhard, Luc Guerraz und Carlo Pierotto realisiert.
Benutzt wird ein ESP32c6
Beim Starten wird zuerst die Waage kalibriert und danach wird auf Gewichtsunterschiede geachtet.
Jeder Gewichtsunterschied wird an die API gesendet, welche den entsprechenden Spielzeugnahmen zurückgibt. Dieser wird dann angezeigt, zusammen mit der Info, ob das Spielzeug hineingelegt oder entfernt wurde.
Falls nicht alle Spielsachen um 18:30 in der Box verräumt sind, kommt alle 5 Minuten eine Nachricht auf dem OLED und über den Lautsprecher, dass aufgeräumt werden soll.
Wenn um 19:00 aufgeräumt wurde, kommt eine Nachricht mit Lob, wenn dann eine Nachricht der Enttäschung.
*/

//Verwendete Bibliotheken
#include "HX711.h" //Waage
#include <Adafruit_GFX.h> //OLED
#include <Adafruit_SSD1306.h> //OLED
#include <WiFi.h> //WIFI
#include <Wire.h> //WIFI
#include "time.h" //Zeit
#include <HTTPClient.h> //HTTP
#include <Arduino_JSON.h> //JSON
#include <Adafruit_NeoPixel.h> //LED Ring
#include "audioplayer.h" // <--- NEU: Audio Player einbinden

// WLAN Zugangsdaten
const char* ssid     = "tinkergarden";
const char* password = "strenggeheim";

const String serialNumber = "xy-xy-xy";
const String baseURL = "https://im04.tim-broenimann.ch/api/physical/";

// API Endpunkte
const String eventServerURL = baseURL + serialNumber + "/event";
const String statusServerURL = baseURL + serialNumber + "/status";
const String addServerURL = baseURL + serialNumber + "/add";

// Variablen für die Zeitsteuerung des Aufräum-Reminders
int letzteGepruefteMinute = -1;
bool tagesFazitGezogen = false;

// Variablen für den Add-Modus
unsigned long letzterAddCheck = 0;
const unsigned long ADD_CHECK_INTERVALL = 3000; // Alle 3 Sekunden abfragen
bool isAddMode = false;

// Zeit (NTP Server)
const char* ntpServer = "pool.ntp.org";
const long  gmtOffset_sec = 3600;      // UTC +1 (Winterzeit) = 3600 Sek.
const int   daylightOffset_sec = 3600; // Sommerzeit-Offset

// Pins der Waage
const int LOADCELL_DOUT_PIN = 4;
const int LOADCELL_SCK_PIN = 5;

//OLED definieren
#define SCREEN_WIDTH 128
#define SCREEN_HEIGHT 64
Adafruit_SSD1306 display(SCREEN_WIDTH, SCREEN_HEIGHT, &Wire, -1);

//Waage initiieren
HX711 scale;

// NeoPixel Ring definieren
#define PIN_NEOPIXEL 10 
#define NUMPIXELS 12 
Adafruit_NeoPixel pixels(NUMPIXELS, PIN_NEOPIXEL, NEO_GRB + NEO_KHZ800);

// Variablen für die LED-Animation
bool showGreenLight = false;
unsigned long greenLightStart = 0;
const unsigned long GREEN_LIGHT_DURATION = 3000; // 3 Sekunden grün leuchten synchron zum Display

// Variablen für die "Lade-Animation" (Blauer Kreis im Add-Modus)
int currentPixel = 0;
unsigned long lastPixelUpdate = 0;
const unsigned long PIXEL_SPEED = 80; // Geschwindigkeit des blauen Punktes

// --- Variablen für die automatische Gewichtserkennung ---
float letztesGesendetesGewicht = 0.0;
float letzterMesswert = 0.0;
unsigned long stabilisierungsTimer = 0;

// Einstellungen für die Auslösung 
const float MIN_GEWICHTS_AENDERUNG = 5.0; // Ab 5g Unterschied wird gesendet
const float RAUSCH_TOLERANZ = 2.0;        // Schwankungen unter 2g beim Hantieren ignorieren
const unsigned long STABILISIERUNGS_ZEIT = 1500; // 1500 Millisekunden muss das Gewicht ruhig liegen

// Funktionsprototypen
void sendWeightToAPI(float weight);
void zeigeReminder(String zeile1, String zeile2, String zeile3);
bool checkAufraeumStatus();
bool checkAddMode();
void sendNewToyToAPI(float weight);
void fillRing(uint8_t r, uint8_t g, uint8_t b);
void triggerGreenLight();

void setup() {
  //Serial Monitor initiieren
  Serial.begin(115200);

  // <--- NEU: Audio Player starten --->
  initAudioPlayer();

  // LEDs starten
  pixels.begin(); 
  pixels.setBrightness(20); 
  pixels.clear();
  pixels.show();
  
  //Display starten (I2C Pins 6 und 7 für ESP32)
  Wire.begin(6, 7);
  if(!display.begin(SSD1306_SWITCHCAPVCC, 0x3C)) {
    Serial.println("Display Fehler!");
    while(true);
  }
  display.clearDisplay();
  display.setTextColor(SSD1306_WHITE);
  display.display();

  // WLAN verbinden
  WiFi.begin(ssid, password);
  while (WiFi.status() != WL_CONNECTED) {
    delay(500);
    Serial.print(".");
    display.clearDisplay();
    display.setTextSize(1);
    display.setCursor(0, 35);
    display.print("WIFI nicht verbunden!");
    display.display();
  }
  
  //Waage starten
  Serial.println("Waage wird initialisiert...");
  scale.begin(LOADCELL_DOUT_PIN, LOADCELL_SCK_PIN);
  display.clearDisplay();
  display.setTextSize(1);
  display.setCursor(0, 10);
  display.print("sortino wird tariert");
  display.setCursor(0, 35);
  display.print("Nichts auflegen!");
  display.display();
  delay(100);
    
  Serial.println("Waage wird tariert. Bitte nichts auflegen!");
  scale.tare();
  Serial.println("Tarieren abgeschlossen.");
  display.clearDisplay();
  display.setTextSize(1);
  display.setCursor(0, 10);
  display.print("sortino");
  display.setCursor(0, 35);
  display.print("Tarierung beendet");
  display.display();
  delay(1000);
    
  //Zeit-Einstellungen laden
  configTime(gmtOffset_sec, daylightOffset_sec, ntpServer);
}

void loop() {

  // ---------------- LED Steuerung (ohne delay) ----------------
  // 1. Wenn das grüne Licht aktiv ist, abwarten bis die Zeit abgelaufen ist
  if (showGreenLight) {
    if (millis() - greenLightStart >= GREEN_LIGHT_DURATION) {
      showGreenLight = false;
      pixels.clear();
      pixels.show();
    }
  } 
  // 2. Ansonsten: Wenn wir im Add-Modus sind, blauen Kreis animieren
  else if (isAddMode) {
    if (millis() - lastPixelUpdate >= PIXEL_SPEED) {
      lastPixelUpdate = millis();
      
      pixels.clear();
      pixels.setPixelColor(currentPixel, pixels.Color(0, 150, 255)); // Blau
      pixels.show();
      
      currentPixel++;
      if (currentPixel >= NUMPIXELS) {
        currentPixel = 0;
      }
    }
  } 
  // 3. Ansonsten: LEDs einfach ausschalten (Normalzustand)
  else {
    pixels.clear();
    pixels.show();
  }
  // -------------------------------------------------------------

  //------------------------------------------------Zeit auf Display--------------------------------------------------
  static unsigned long letzteDisplayZeit = 0;
  if (millis() - letzteDisplayZeit >= 1000) {
    letzteDisplayZeit = millis();
    struct tm timeinfo;
    if(getLocalTime(&timeinfo)) {
      
      // Nur die normale Uhrzeit zeichnen, wenn wir nicht im Add-Modus sind
      if (!isAddMode) {
        display.clearDisplay();
        display.setTextSize(1);
        display.setCursor(0, 10);
        display.printf("%02d.%02d.%04d", timeinfo.tm_mday, timeinfo.tm_mon + 1, timeinfo.tm_year + 1900);

        display.setTextSize(2);
        display.setCursor(0, 35);
        display.printf("%02d:%02d:%02d", timeinfo.tm_hour, timeinfo.tm_min, timeinfo.tm_sec);
        display.display();
      }

      // ---------------- Aufräum-Kontrolle ----------------
      int stunde = timeinfo.tm_hour;
      int minute = timeinfo.tm_min;

      // Um Mitternacht die Variablen für den nächsten Tag zurücksetzen
      if (stunde == 0) {
        tagesFazitGezogen = false;
        letzteGepruefteMinute = -1;
      }

      // 1. Zuerst prüfen: Ist es genau 19:00 Uhr? (Finales Fazit)
      if (stunde == 19 && minute == 00) {
        if (!tagesFazitGezogen) { 
          tagesFazitGezogen = true; 
          if (checkAufraeumStatus()) {
            playTrack(3); // <--- NEU: Erfolgs-Sound abspielen
            zeigeReminder("Bravo,", "du hast", "aufgeraeumt!");
          } else {
            playTrack(1); // <--- NEU: Schade-Sound abspielen
            zeigeReminder("Schade,", "du hast heute", "nicht aufgeraeumt.");
          }
        }
      } 
      // 2. Ansonsten: Ist es zwischen 18:30 und 18:55? (Normale Erinnerung)
      else if (stunde == 18 && minute >= 30) {
        if (minute % 5 == 0 && minute != letzteGepruefteMinute) {
          letzteGepruefteMinute = minute; 
          if (!checkAufraeumStatus()) {
            playTrack(2); // <--- NEU: Erinnerungs-Sound abspielen
            zeigeReminder("Bitte", "raeume deine", "Spielsachen auf!");
          }
        }
      }
      // ---------------------------------------------------------
    } 
  } 

  //------------------------------------------------Add-Mode Abfrage--------------------------------------------------
  if (millis() - letzterAddCheck >= ADD_CHECK_INTERVALL) {
    letzterAddCheck = millis();
    isAddMode = checkAddMode();
    
    // Wenn der Modus aktiv ist, auf dem Display anzeigen
    if (isAddMode) {
      display.clearDisplay();
      display.setTextSize(1);
      display.setCursor(0, 10);
      display.print("Lern-Modus aktiv!");
      display.setCursor(0, 35);
      display.print("Neues Spielzeug");
      display.setCursor(0, 50);
      display.print("jetzt auflegen...");
      display.display();
    }
  }

  //------------------------------------------------Automatische Gewichtserkennung--------------------------------------------------
  if (scale.is_ready()) {
    // Nur 3 Messungen abfragen, damit der Loop schnell bleibt
    long reading = scale.get_value(3);
    float aktuellesGewicht = reading / 426.0;

    // 1. Prüfen, ob sich das Gewicht gerade stark bewegt
    if (abs(aktuellesGewicht - letzterMesswert) > RAUSCH_TOLERANZ) {
      stabilisierungsTimer = millis(); // Objekt wird gerade bewegt, Timer neu starten
      letzterMesswert = aktuellesGewicht;
    } 
    // 2. Das Gewicht bewegt sich nicht mehr
    else {
      // Ist es schon lange genug ruhig?
      if ((millis() - stabilisierungsTimer) > STABILISIERUNGS_ZEIT) {
        
        // Differenz zum zuletzt gesendeten Zustand berechnen
        float differenz = aktuellesGewicht - letztesGesendetesGewicht;

        // 3. Prüfen, ob die Differenz gross genug für einen API-Call ist
        if (abs(differenz) >= MIN_GEWICHTS_AENDERUNG) {
          
          Serial.print("Differenz erkannt: ");
          Serial.println(differenz);

          // ------ Unterscheidung zwischen Add-Modus und Normal-Modus ------
          if (isAddMode && differenz > 0) { 
            // Es wurde etwas aufgelegt und Add-Modus ist an
            sendNewToyToAPI(differenz);
            isAddMode = false; // Nach dem Erfassen lokal wieder ausschalten
          } else {
            // Normaler Modus
            sendWeightToAPI(differenz);
          }
          
          // Das neue Gewicht als Grundwert für die nächste Messung speichern
          letztesGesendetesGewicht = aktuellesGewicht;
          
          // 3 Sekunden warten, damit man das Display ablesen kann
          // Das friert auch das grüne Licht für exakt 3 Sekunden ein, was super aussieht!
          delay(3000);
          
          // Danach den Timer resetten, um Doppelauslösungen zu verhindern
          stabilisierungsTimer = millis(); 
        }
      }
    }
  }
}

// ===================================================================================================
// HILFSFUNKTIONEN FÜR LEDS
// ===================================================================================================

// Füllt den ganzen Ring in einer bestimmten Farbe
void fillRing(uint8_t r, uint8_t g, uint8_t b) {
  for(int i=0; i<NUMPIXELS; i++) {
    pixels.setPixelColor(i, pixels.Color(r, g, b));
  }
  pixels.show();
}

// Löst das grüne Leuchten aus
void triggerGreenLight() {
  showGreenLight = true;
  greenLightStart = millis();
  fillRing(0, 255, 0); // Grün
}


// ===================================================================================================
// HILFSFUNKTIONEN FÜR APIS UND DISPLAY
// ===================================================================================================

// Funktion zum Senden des Gewichts an die API und Auswerten der Antwort (Normaler Modus)
void sendWeightToAPI(float weight) {
  if (WiFi.status() == WL_CONNECTED) {
    HTTPClient http;
    http.begin(eventServerURL);
    
    http.addHeader("Content-Type", "application/json");

    JSONVar dataObject;
    dataObject["weight"] = weight; 
    String jsonString = JSON.stringify(dataObject);

    Serial.print("Sende JSON an API: ");
    Serial.println(jsonString);

    int httpResponseCode = http.POST(jsonString);

    if (httpResponseCode > 0) {
      String response = http.getString();
      Serial.printf("Erfolgreich! Code: %d\n", httpResponseCode);
      Serial.println("Antwort der API: " + response);

      JSONVar responseObject = JSON.parse(response);

      if (JSON.typeof(responseObject) == "undefined") {
        Serial.println("Fehler beim Parsen der API-Antwort!");
      } else {
        String itemName = (const char*) responseObject["data"]["name"];
        int movement = (int) responseObject["data"]["movement"];

        // Prüfen, ob der Artikel erkannt wurde (Name nicht leer und nicht "null")
        if (itemName != "" && itemName != "null") {
          String aktion = (movement == 0) ? "herausgenommen" : "hereingelegt";

          // Wenn der Artikel HEREINGELEGT (movement == 1) wurde, grün leuchten lassen
          if (movement == 1) {
            triggerGreenLight();
          }

          display.clearDisplay();
          display.setTextSize(1);
          display.setCursor(0, 5);
          display.print("Du hast:");
          
          display.setTextSize(1);
          display.setCursor(0, 20);
          display.print(itemName);
          
          display.setTextSize(1);
          display.setCursor(0, 45);
          display.print(aktion);
          
          display.display();
        } else {
          Serial.println("Artikel nicht erkannt. OLED bleibt unverändert.");
        }
      }
    } else {
      Serial.printf("Fehler beim Senden. Code: %d\n", httpResponseCode);
      display.clearDisplay();
      display.setTextSize(1);
      display.setCursor(0, 25);
      display.print("API Fehler!");
      display.display();
    }
    http.end();
  } else {
    Serial.println("Senden fehlgeschlagen: WLAN nicht verbunden!");
  }
}

// Funktion, um das NEUE Spielzeug an die API zu senden (Lern-Modus)
void sendNewToyToAPI(float weight) {
  if (WiFi.status() == WL_CONNECTED) {
    HTTPClient http;
    http.begin(addServerURL); 
    
    http.addHeader("Content-Type", "application/json");

    JSONVar dataObject;
    dataObject["weight"] = weight; 
    String jsonString = JSON.stringify(dataObject);

    Serial.print("Sende NEUES Spielzeug an API: ");
    Serial.println(jsonString);

    int httpResponseCode = http.POST(jsonString);

    if (httpResponseCode > 0) {
      String response = http.getString();
      Serial.printf("Erfolgreich! Code: %d\n", httpResponseCode);
      Serial.println("Antwort der API: " + response);

      // JSON Antwort parsen
      JSONVar responseObject = JSON.parse(response);

      if (JSON.typeof(responseObject) == "undefined") {
        Serial.println("Fehler beim Parsen der API-Antwort!");
        
        // Fallback, falls das JSON nicht gelesen werden konnte
        triggerGreenLight();
        
        display.clearDisplay();
        display.setTextSize(1);
        display.setCursor(0, 20);
        display.print("Spielzeug");
        display.setCursor(0, 40);
        display.print("gespeichert!");
        display.display();
      } else {
        // Name aus dem JSON lesen 
        String itemName = (const char*) responseObject["data"]["name"];
        
        triggerGreenLight();
        
        // Auf dem Display anzeigen
        display.clearDisplay();
        display.setTextSize(1);
        display.setCursor(0, 5);
        display.print("Neu erfasst:");
        
        display.setTextSize(1);
        display.setCursor(0, 25);
        display.print(itemName); 
        
        display.setTextSize(1);
        display.setCursor(0, 50);
        display.print("gespeichert!");
        display.display();
      }
    } else {
      Serial.printf("Fehler beim Erfassen. Code: %d\n", httpResponseCode);
    }
    http.end();
  } else {
    Serial.println("Senden fehlgeschlagen: WLAN nicht verbunden!");
  }
}

// Funktion, um eine Nachricht kurz auf dem OLED anzuzeigen
void zeigeReminder(String zeile1, String zeile2, String zeile3) {
  display.clearDisplay();
  display.setTextSize(1);
  display.setCursor(0, 10);
  display.print(zeile1);
  display.setCursor(0, 30);
  display.print(zeile2);
  display.setCursor(0, 50);
  display.print(zeile3);
  display.display();
  delay(5000); 
}

// Funktion, um den Status abzufragen (GET - Aufräumkontrolle)
bool checkAufraeumStatus() {
  bool istAufgeraeumt = false;
  if (WiFi.status() == WL_CONNECTED) {
    HTTPClient http;
    http.begin(statusServerURL);
    int httpResponseCode = http.GET();

    if (httpResponseCode > 0) {
      String response = http.getString();
      Serial.println("Status API Antwort: " + response);
      JSONVar responseObject = JSON.parse(response);

      if (JSON.typeof(responseObject) != "undefined") {
        istAufgeraeumt = (bool) responseObject["data"]["all_in_box"]; 
      }
    } else {
      Serial.printf("Fehler beim Status-Abruf. Code: %d\n", httpResponseCode);
    }
    http.end();
  }
  return istAufgeraeumt;
}

// Funktion, um zu prüfen, ob ein neues Spielzeug hinzugefügt werden soll (GET)
bool checkAddMode() {
  bool mode = false;
  if (WiFi.status() == WL_CONNECTED) {
    HTTPClient http;
    http.begin(addServerURL);
    int httpResponseCode = http.GET();

    if (httpResponseCode > 0) {
      String response = http.getString();
      JSONVar responseObject = JSON.parse(response);

      if (JSON.typeof(responseObject) != "undefined") {
        mode = (bool) responseObject["data"]["add_mode"]; 
      }
    }
    http.end();
  }
  return mode;
}

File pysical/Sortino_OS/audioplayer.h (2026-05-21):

#ifndef AUDIOPLAYER_H
#define AUDIOPLAYER_H

#include <Arduino.h>

// Neue Verkabelung:
// ESP GPIO21 (gelb)  -> MP3 RX
// ESP GPIO22 (grün)  -> MP3 TX
// ESP GPIO23 (türkis)-> Transistor-Basis für MP3-GND
HardwareSerial myMP3(1);

#define RX_PIN 21
#define TX_PIN 22
#define MP3_GND_CONTROL_PIN 23
#define PLAYER_BAUD 9600

#define PLAY_W_INDEX 0x41
#define SET_VOLUME   0x31
#define SEL_DEV      0x35
#define DEV_TF       0x01

// 5-Byte-Befehl: 7E 03 CMD DATA EF
void sendMP3Command5(uint8_t command, uint8_t data) {
  uint8_t sendBuf[5] = {
    0x7e,
    0x03,
    command,
    data,
    0xef
  };

  myMP3.write(sendBuf, 5);
  delay(100);
}

// 6-Byte-Befehl: 7E 04 CMD DATA_H DATA_L EF
void sendMP3Command6(uint8_t command, uint16_t data) {
  uint8_t sendBuf[6] = {
    0x7e,
    0x04,
    command,
    (uint8_t)(data >> 8),
    (uint8_t)(data & 0xff),
    0xef
  };

  myMP3.write(sendBuf, 6);
  delay(100);
}

void initAudioPlayer() {
  pinMode(MP3_GND_CONTROL_PIN, OUTPUT);

  // Player zuerst sauber einschalten
  digitalWrite(MP3_GND_CONTROL_PIN, HIGH);
  delay(1000);

  myMP3.begin(PLAYER_BAUD, SERIAL_8N1, RX_PIN, TX_PIN);

  Serial.println("audio player starting...");

  // SD-Karte auswählen
  sendMP3Command5(SEL_DEV, DEV_TF);
  delay(300);

  // Lautstärke 0 bis 30
  sendMP3Command5(SET_VOLUME, 30);
  delay(300);

  Serial.println("audio player ready");
}

void playTrack(int trackNumber) {
  if (trackNumber < 1) return;

  sendMP3Command6(PLAY_W_INDEX, (uint16_t)trackNumber);
}

#endif

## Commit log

2026-05-13 HTML und CSS für Login und Register
2026-05-13 feat: add physical api for esp32
2026-05-15 Register Button fehlte noch
2026-05-21 Physical computing added
    [3d Druck.3mf]
2026-05-21 Bug Fix Button
2026-05-21 Logout Button zurückgebracht
2026-05-22 TOY Page update
    - Löschen Funktion
    - Reihenfolge der Liste
    - Vorbereitung für Bearbeitungs-Funktion
2026-06-10 Read-Me: Features
    Welche Features waren geplant?
    Welche wurden weg gelassen und wieso?
2026-06-10 Styling Action Button (Spielzeug hinzufügen)
2026-06-11 "in Kiste" Button grün gemacht
2026-06-13 Minimale Design-Korrekturen
    Buttons Profil bearbeiten (Einstellungen & Profil)
2026-06-13 Visuelle Optimierung Popup-Buttons
    Abbrechen wird grau und gefährliche Buttons Rot.
    Ausserdem: Icon für Kisten wird ausgetauscht.
